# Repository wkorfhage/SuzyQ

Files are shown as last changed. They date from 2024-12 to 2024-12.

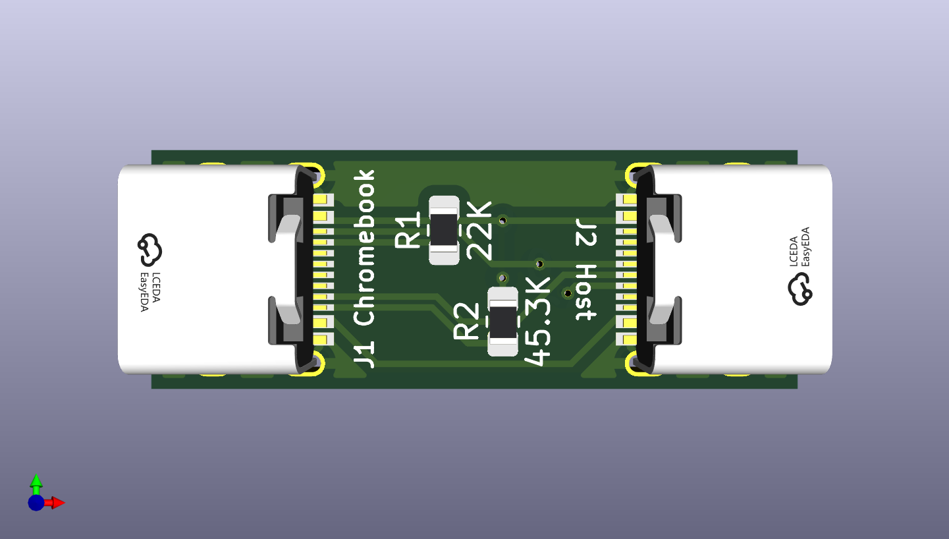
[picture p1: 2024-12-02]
docs/v1.0-SuzyQ-top.png

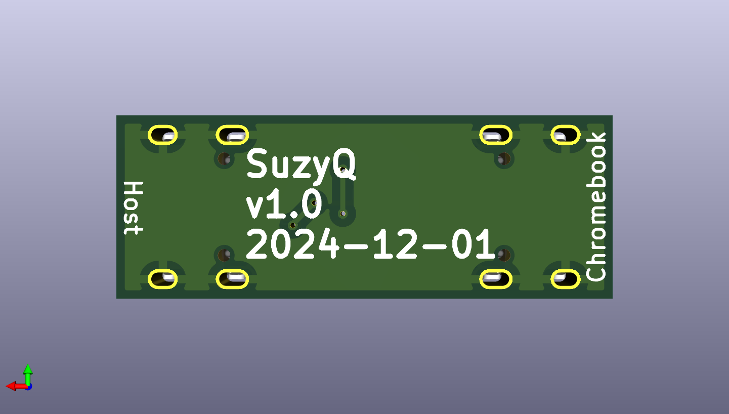
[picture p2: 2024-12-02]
docs/v1.0-SuzyQ-bottom.png

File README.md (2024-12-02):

# SusyQ
SusyQ adapter for a Chromebook using the connection definition on
 [the hdctools website](https://chromium.googlesource.com/chromiumos/third_party/hdctools/+/HEAD/docs/ccd.md#SuzyQ-SuzyQable).

 This uses the following parts

 |Description|Part Number|LCSC Part Number|Quantity|
 |16P USB-C socket|USB-C_SMD-TYPE-C-31-M-12|C165948|2|
 |22K 0805 SMD resistor|||1|
 |45.3K 0805 SMD resistor|||1|

 This ignores the impedance standards for the USB data lines and is just a standard 2-layer board.

 The board is 11 mm in diameter, so you can insulate it with clear heat-shrink tubing 15-20 mm in diameter

 This project uses KiCad 8

## Versions

### 1.0

This version uses 2 USB-C female connectors.

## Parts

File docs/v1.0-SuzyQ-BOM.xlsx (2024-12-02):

Reference | Value | Description | Footprint | LCSC Part
J1 | Chromebook | 16P 5A Female Type-C SMD USB Connector | LCSC:USB-C_SMD-TYPE-C-31-M-12 | C165948
J2 | Host | 16P 5A Female Type-C SMD USB Connector | LCSC:USB-C_SMD-TYPE-C-31-M-12 | C165948
R1 | 22K | Resistor | Resistor_SMD:R_0805_2012Metric_Pad1.20x1.40mm_HandSolder
R2 | 45.3K | Resistor | Resistor_SMD:R_0805_2012Metric_Pad1.20x1.40mm_HandSolder

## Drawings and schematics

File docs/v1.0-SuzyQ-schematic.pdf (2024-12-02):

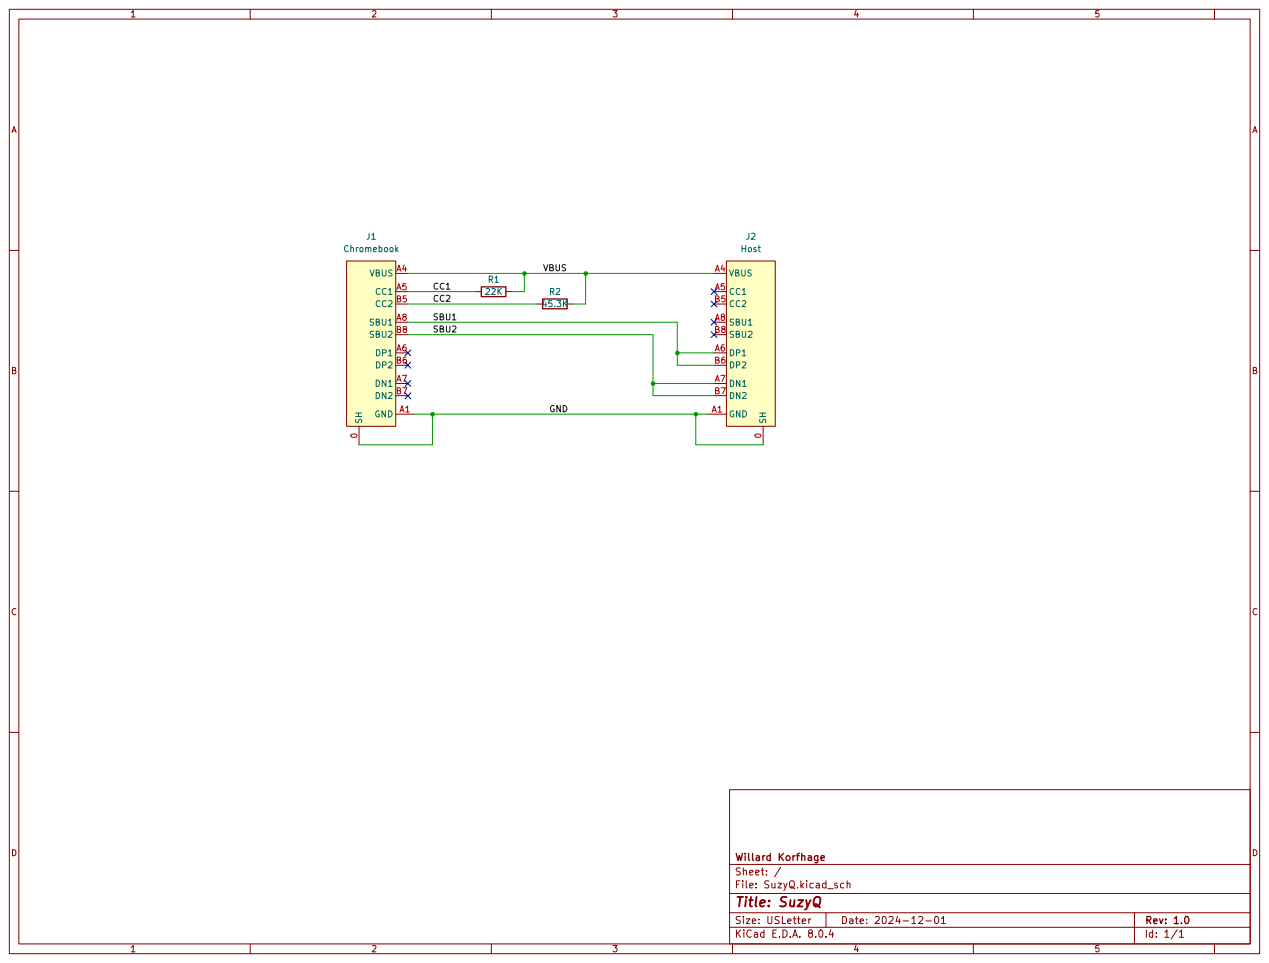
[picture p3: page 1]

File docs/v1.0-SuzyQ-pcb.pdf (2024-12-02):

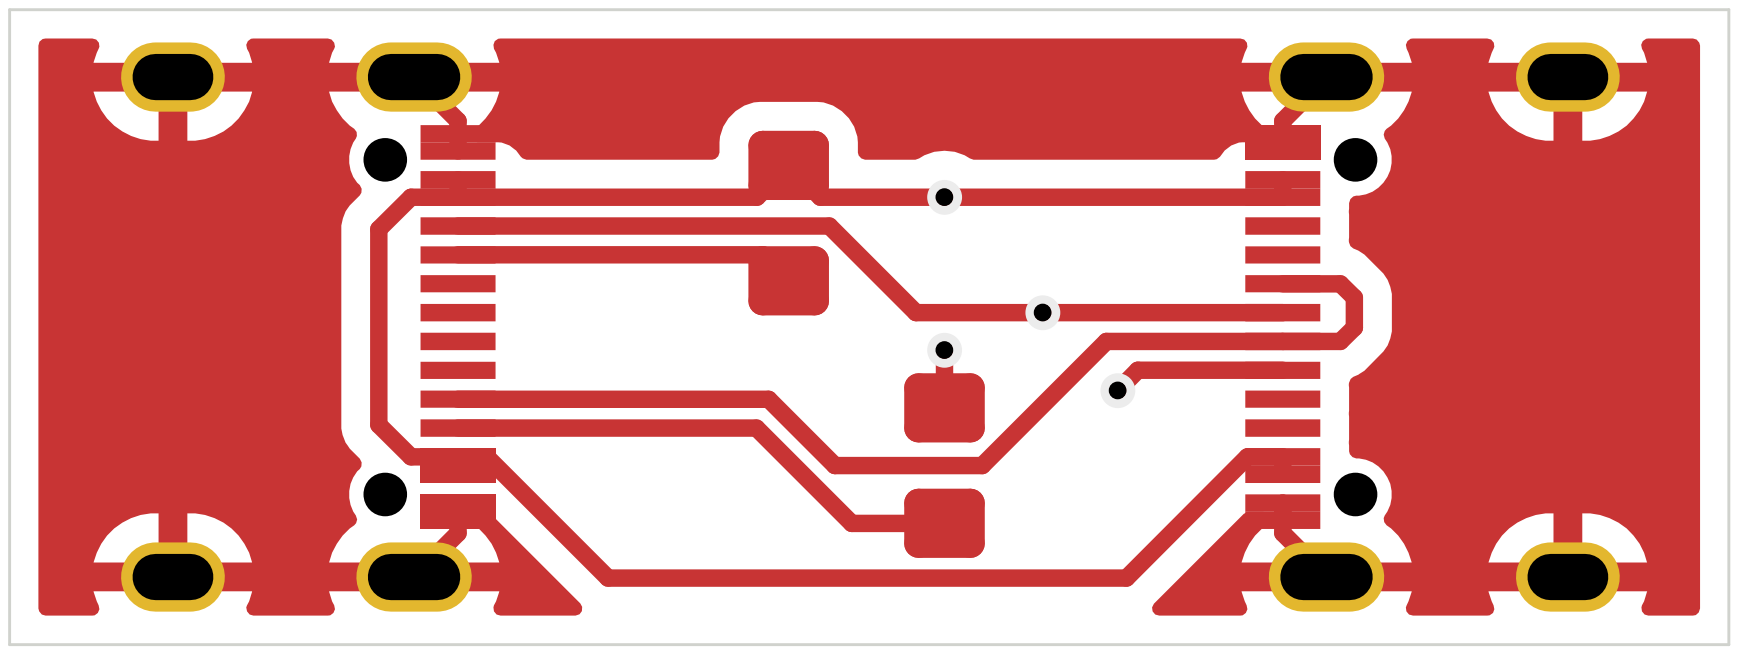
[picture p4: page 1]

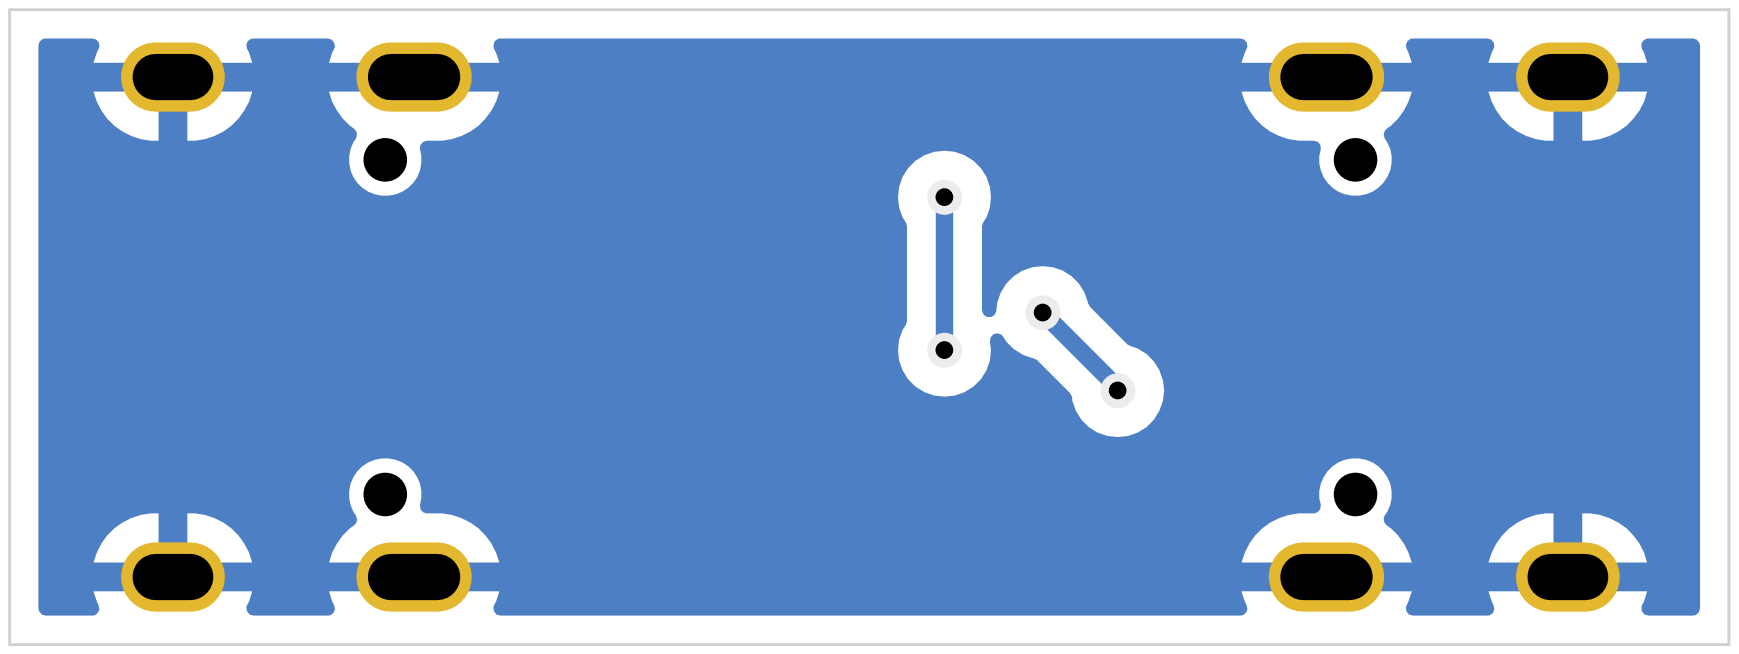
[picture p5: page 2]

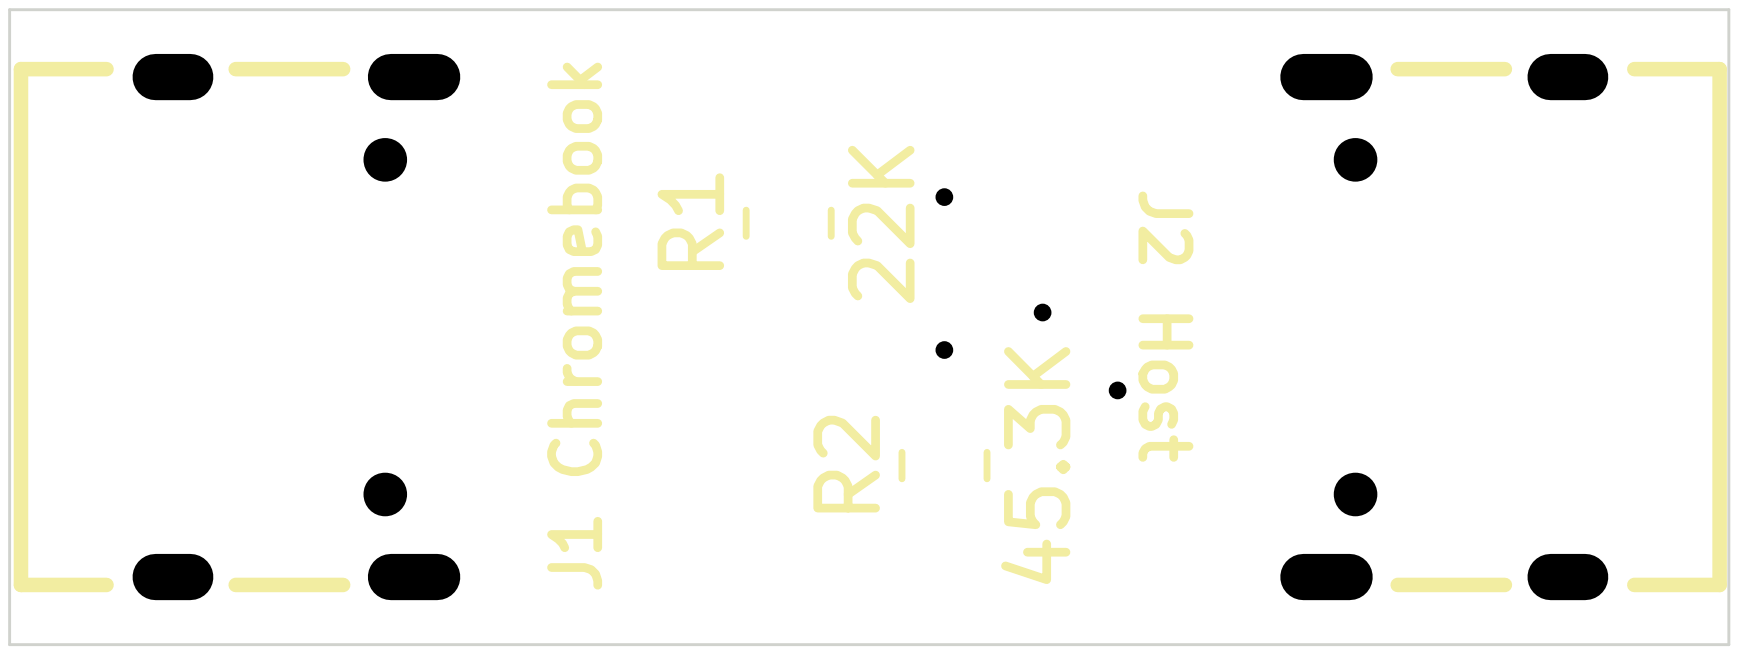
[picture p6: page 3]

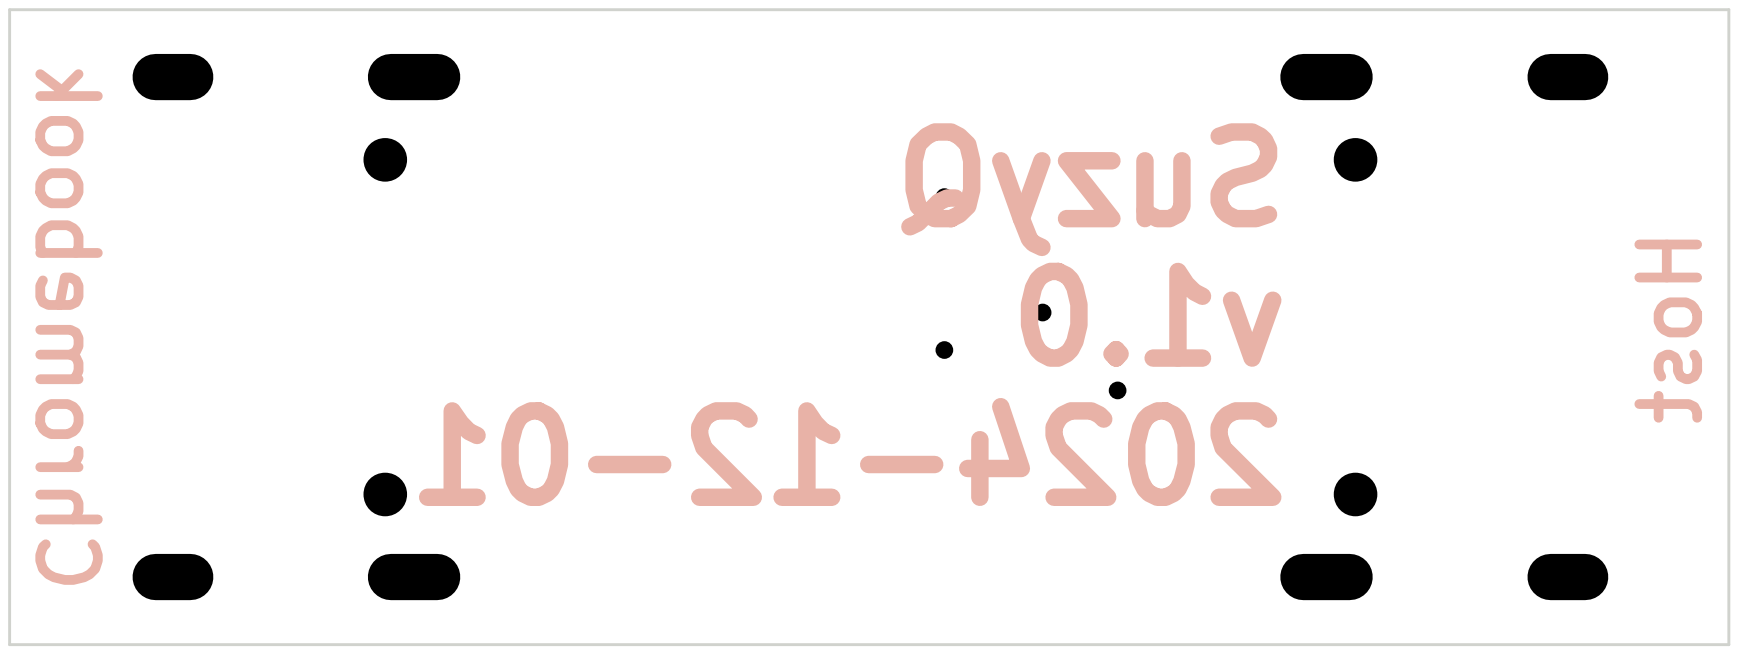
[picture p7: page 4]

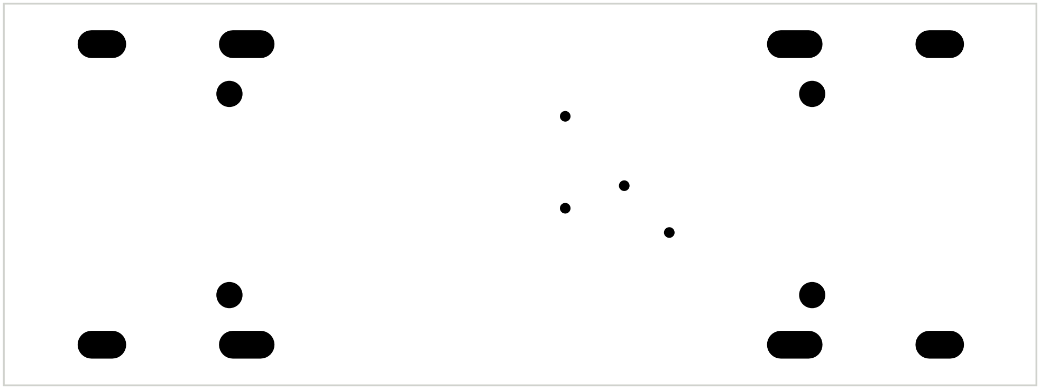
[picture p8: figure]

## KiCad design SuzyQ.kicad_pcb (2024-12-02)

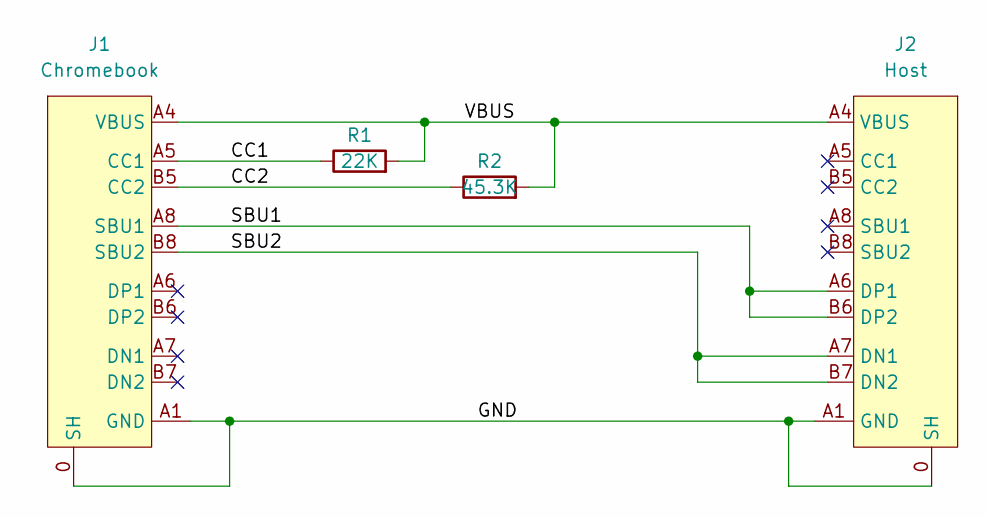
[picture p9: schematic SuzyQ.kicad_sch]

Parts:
J1: Chromebook; USB-C_SMD-TYPE-C-31-M-12; LCSC Part C165948
J2: Host; USB-C_SMD-TYPE-C-31-M-12; LCSC Part C165948
R1: 22K; R_0805_2012Metric_Pad1.20x1.40mm_HandSolder
R2: 45.3K; R_0805_2012Metric_Pad1.20x1.40mm_HandSolder

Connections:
/CC1: J1.A5 (CC1), R1.1
/CC2: J1.B5 (CC2), R2.1
/GND: J1.0 (SH), J1.1 (SH), J1.2 (SH), J1.3 (SH), J1.A1 (GND), J1.A12 (GND), J1.B1 (GND), J1.B12 (GND), J2.0 (SH), J2.1 (SH), J2.2 (SH), J2.3 (SH), J2.A1 (GND), J2.A12 (GND), J2.B1 (GND), J2.B12 (GND)
/SBU1: J1.A8 (SBU1), J2.A6 (DP1), J2.B6 (DP2)
/SBU2: J1.B8 (SBU2), J2.A7 (DN1), J2.B7 (DN2)
/VBUS: J1.A4 (VBUS), J1.A9 (VBUS), J1.B4 (VBUS), J1.B9 (VBUS), J2.A4 (VBUS), J2.A9 (VBUS), J2.B4 (VBUS), J2.B9 (VBUS), R1.2, R2.2

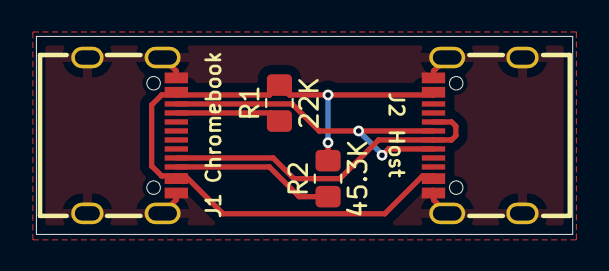
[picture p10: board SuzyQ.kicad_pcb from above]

Board: 2 copper layers, 29.8 x 11.0 mm, 4 parts (0 on the bottom side), 6 nets.

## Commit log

2024-12-02 version 1.0 files
    [SuzyQ-B_Cu.gbl, SuzyQ-B_Mask.gbs, SuzyQ-B_Paste.gbp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]
2024-12-02 Forgot to save schematic
